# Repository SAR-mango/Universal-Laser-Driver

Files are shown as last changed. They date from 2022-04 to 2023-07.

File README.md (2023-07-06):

# Universal Laser Driver
Solves the problem of having to match batteries, laser drivers, and diodes based on input and output voltage and current requirements.

## Applications
Intended for low-power laser pointers where space is minimal.

Especially well suited for builds utilizing the Leadlight Pen Host, because the PCB is designed to fit in the plastic carrier that normally holds the switch board. The Leadlight Pen Host requires two 10440-sized battery cells, and the Universal Laser Driver allows the user to swap between AAA alkaline and 10440 Li-ion cells without worrying about damaging the driver or not having sufficient voltage to power the diode.

## Specifications
Vin: 2.25–9V

Vout: 1–7V

Iout: 0–200mA

These can very significantly. Lower Vin and/or higher Vout (due to the nonlinear nature of laser diodes) would result in a lower maximum Iout. A lower Iout setting would extend the Vin and Vout ranges.

## Project Updates
**July 2023**: The test board has been shown to reliably produce stable currents between 0 and 200mA using a test load with six standard silicon diodes and one 1Ω resistor in series. Minimal noise was found in the output current waveform, especially below 20MHz. Noise pulses were no more than several nanoseconds long. Therefore, the Universal Laser Driver is unlikely to cause damage or reduced reliability to even the most delicate laser diodes.

The version of the driver meant for the Leadlight Pen Host will be updated to reflect the current schematic for the test board.

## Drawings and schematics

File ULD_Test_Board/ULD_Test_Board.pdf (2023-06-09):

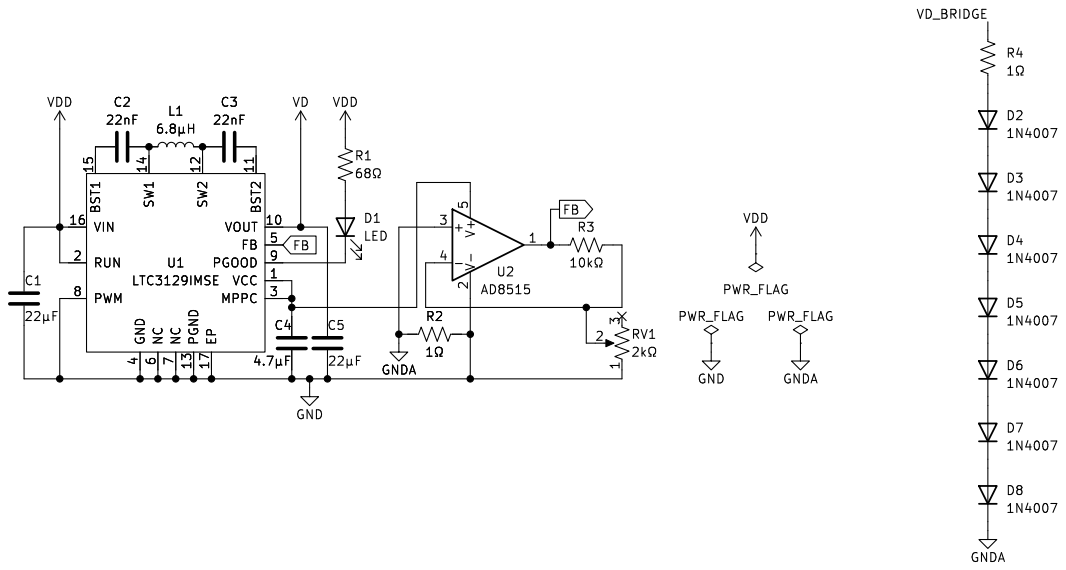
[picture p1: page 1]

Id: 1/1 Title: ULD Test Board

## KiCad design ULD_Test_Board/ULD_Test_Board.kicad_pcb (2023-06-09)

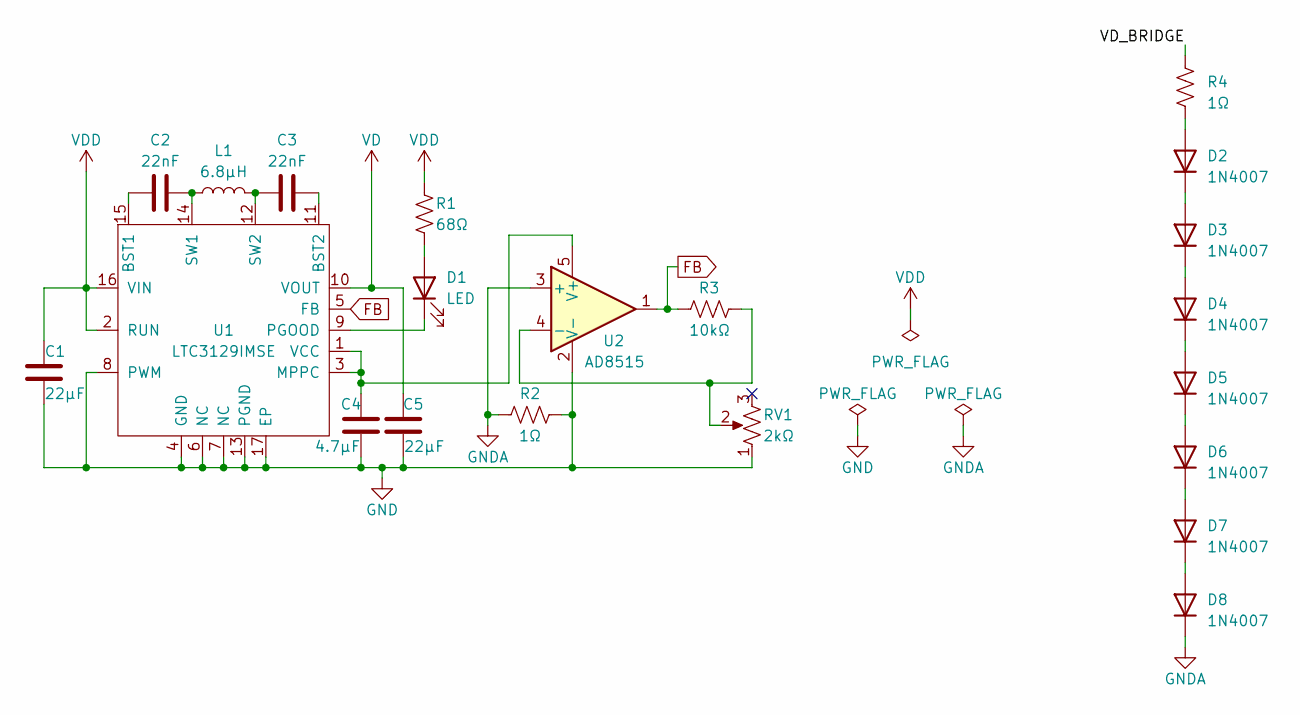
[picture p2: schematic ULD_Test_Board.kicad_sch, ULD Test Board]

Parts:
C1, C5: 22µF; C_1210_3225Metric_Pad1.33x2.70mm_HandSolder
C2, C3: 22nF; C_0805_2012Metric_Pad1.18x1.45mm_HandSolder
C4: 4.7µF; C_1210_3225Metric_Pad1.33x2.70mm_HandSolder
D1: LED; LED_0805_2012Metric_Pad1.15x1.40mm_HandSolder
D2, D3, D4, D5, D6, D7, D8: 1N4007; D_SOD-123F
L1: 6.8µH; L_Taiyo-Yuden_MD-4040
R1: 68Ω; R_0805_2012Metric_Pad1.20x1.40mm_HandSolder
R2, R4: 1Ω; R_1210_3225Metric_Pad1.30x2.65mm_HandSolder
R3: 10kΩ; R_0805_2012Metric_Pad1.20x1.40mm_HandSolder
RV1: 2kΩ; Potentiometer_Bourns_TC33X_Vertical
U1: LTC3129IMSE; MSOP-16-1EP_3x4.039mm_P0.5mm_EP1.651x2.845mm
U2: AD8515; SOT-23-5_HandSoldering

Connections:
/VD_BRIDGE: R4.1
FB: R3.2, U1.5 (FB), U2.1
GND: C1.2, C4.2, C5.1, R2.2, RV1.1, U1.4 (GND), U1.6 (NC), U1.7 (NC), U1.8 (PWM), U1.13 (PGND), U1.17 (EP), U2.2 (V-)
GNDA: D8.1 (K), R2.1, U2.3 (+)
unnamed: D1.2 (A), R1.2
unnamed: D1.1 (K), U1.9 (PGOOD)
unnamed: D2.2 (A), R4.2
unnamed: D2.1 (K), D3.2 (A)
unnamed: D3.1 (K), D4.2 (A)
unnamed: D4.1 (K), D5.2 (A)
unnamed: D5.1 (K), D6.2 (A)
unnamed: D6.1 (K), D7.2 (A)
unnamed: D7.1 (K), D8.2 (A)
unnamed: C2.1, U1.15 (BST1)
unnamed: C3.2, U1.11 (BST2)
unnamed: C4.1, U1.1 (VCC), U1.3 (MPPC), U2.5 (V+)
unnamed: C2.2, L1.1, U1.14 (SW1)
unnamed: C3.1, L1.2, U1.12 (SW2)
unnamed: R3.1, RV1.2, U2.4 (-)
VD: C5.2, U1.10 (VOUT)
VDD: C1.1, R1.1, U1.2 (RUN), U1.16 (VIN)

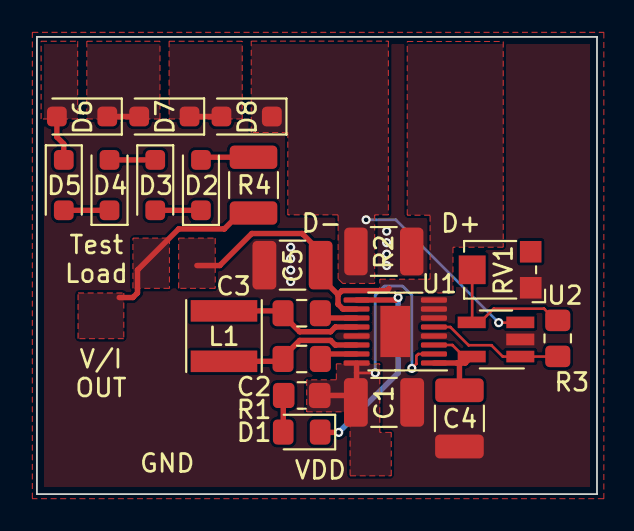
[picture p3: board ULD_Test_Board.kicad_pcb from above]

Board: 2 copper layers, 31.1 x 25.4 mm, 21 parts (0 on the bottom side), 20 nets.

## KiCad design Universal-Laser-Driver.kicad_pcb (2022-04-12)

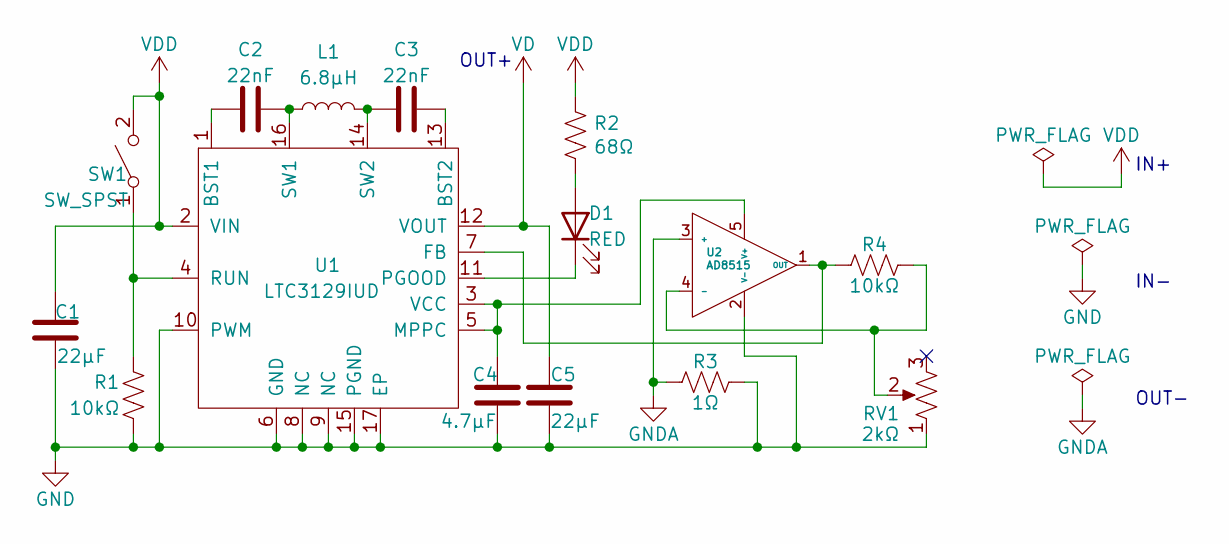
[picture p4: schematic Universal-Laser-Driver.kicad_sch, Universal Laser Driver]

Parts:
C1, C5: 22µF; C_0603_1608Metric; MPN CL10A226MO7JZNC
C2, C3: 22nF; C_0402_1005Metric; MPN C1005X7R1E223K050BB
C4: 4.7µF; C_0402_1005Metric; MPN CL05A475MP5NRNC
D1: RED; LED_0402_1005Metric; MPN 5988A10107F
L1: 6.8µH; L_Taiyo-Yuden_MD-4040; MPN LQH44PH6R8MPRL
R1, R4: 10kΩ; R_0402_1005Metric; MPN ERJ-PA2F1002X
R2: 68Ω; R_0402_1005Metric; MPN ERJ-U02J680X
R3: 1Ω; R_0402_1005Metric; MPN MCS0402MC1008FE000
RV1: 2kΩ; Potentiometer_Bourns_TC33X_Vertical; MPN TC33X-2-202E
SW1: SW_SPST; WUERTH_434121050836; MPN 434121050836
U1: LTC3129IUD; VQFN-16-1EP_3x3mm_P0.5mm_EP1.68x1.68mm; MPN LTC3129IUD
U2: AD8515; SOT-353_SC-70-5; MPN AD8515AKS-REEL7

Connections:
GND: C1.1, C4.2, C5.2, R1.2, R3.1, RV1.1, U1.6 (GND), U1.8 (NC), U1.9 (NC), U1.10 (PWM), U1.15 (PGND), U1.17 (EP), U2.2 (V-)
GNDA: R3.2, U2.3 (+)
unnamed: C2.1, L1.1, U1.16 (SW1)
unnamed: C2.2, U1.1 (BST1)
unnamed: C3.1, U1.13 (BST2)
unnamed: C3.2, L1.2, U1.14 (SW2)
unnamed: C4.1, U1.3 (VCC), U1.5 (MPPC), U2.5 (V+)
unnamed: D1.1 (K), U1.11 (PGOOD)
unnamed: D1.2 (A), R2.2
unnamed: R1.1, SW1.1 (A), U1.4 (RUN)
unnamed: R4.1, RV1.2, U2.4 (-)
unnamed: R4.2, U1.7 (FB), U2.1 (OUT)
VD: C5.1, U1.12 (VOUT)
VDD: C1.2, R2.1, SW1.2 (B), U1.2 (VIN)

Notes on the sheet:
IN-
IN+
OUT-
OUT+

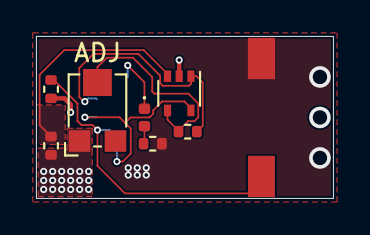
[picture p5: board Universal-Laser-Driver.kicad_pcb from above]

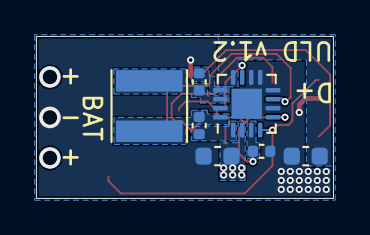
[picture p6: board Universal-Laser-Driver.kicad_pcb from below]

Board: 2 copper layers, 16.5 x 9.0 mm, 15 parts (7 on the bottom side), 14 nets.

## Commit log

2021-09-14 Added all project files
    [Universal-Laser-Driver.kicad_pcb, Universal-Laser-Driver.sch]
2021-09-26 Minor changes for clarity
    [Universal-Laser-Driver.sch]
2021-11-07 Fixed mislabeled net in schematic
    [Universal-Laser-Driver.sch]
2022-04-12 Updated to KiCAD 6
    [Universal-Laser-Driver.kicad_pcb, Universal-Laser-Driver.kicad_sch, Universal-Laser-Driver.sch]
2022-06-07 Created Universal-Laser-Driver-2022-06-07_112458.zip
2022-06-08 Updated schematic PDF
2023-06-09 add test board project folder/files
    [ULD_Test_Board-B_Cu.gbl, ULD_Test_Board-B_Mask.gbs, ULD_Test_Board-B_Silkscreen.gbo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]
